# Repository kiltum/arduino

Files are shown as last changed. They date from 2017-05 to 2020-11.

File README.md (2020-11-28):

# Arduino shield for automation purposes

ATTN: This is picture of very old board. I havent new pictures

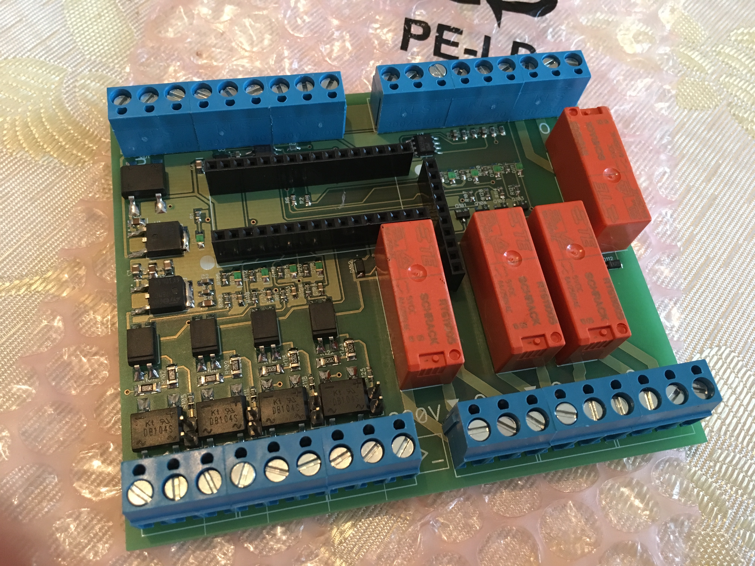
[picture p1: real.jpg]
Ready for using


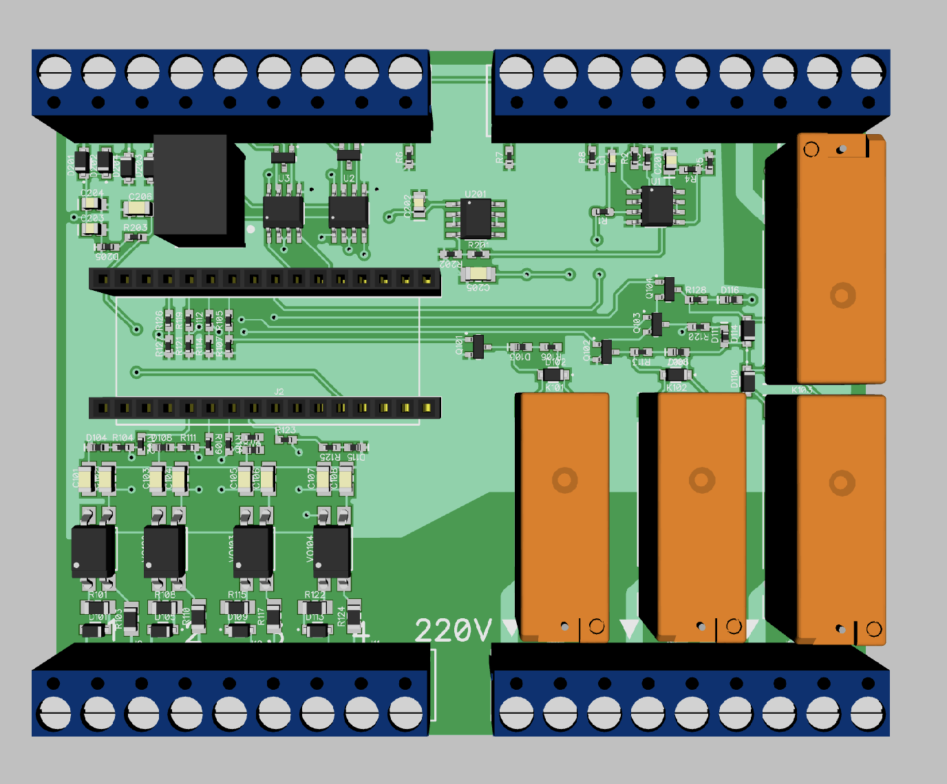
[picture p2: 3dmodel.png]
How it should look


What this shield can do?
- Work with any Arduino Nano
- Work from 15-30 AC/DC. 
- Have 4x220v sensor
- Have 4x8A switch relay
- Have 0-10V output
- Have two RS-485
- 3 PT1000/pulled down analog input

## Pin-out for auduio

- D2,D3,D4 - TX,RX and RE/DE of 485
- D11, D12, D13 - for second 485
- D5 - PWM output for 0-10V
- D6 - PWM output for second 0-10V
- D7-D10 - control for switch relay 1-4
- A4,A5,A6,A7 - pulled down input for PT1000
- A0-A3 - sensors input

## Pin-out for board

Take board like on picture

### Top. Left-to-right

- 1 - power in POSITIVE
- 2 - GND
- 3 - RS485B
- 4 - RS485A
- 5 - RS485B2
- 7 - RS485A2
- 6 - GND
- 8 - 5V
- 9 - A4

separator

- 10 - A5
- 11 - A6 
- 12 - A7
- 13 - 0-10V output 2
- 14 - 0-10V output 1
- 15 - GND
- 16 - R4 closed
- 17 - R4 open	
- 18 - R4 ground

### Bottom, left to right

- 1 - Sensor 1 220V / 24V Positive
- 2 - Sensor 1
- 3 - Sensor 2 220v / 24V Positive
- 4 - Sensor 2
- 5 - Sensor 3 220v / 24V Positive
- 6 - Sensor 3
- 7 - Sensor 4 220v / 24V Positive
- 8 - Sensor 4
- 9 - not connected

separator

- 10 - R1 ground
- 11 - R1 closed
- 12 - R1 open
- 13 - R2 ground 
- 14 - R2 closed
- 15 - R2 open
- 16 - R3 ground
- 17 - R3 close
- 18 - R3 open

## License

Do what you want. I do not rely for anything you do.

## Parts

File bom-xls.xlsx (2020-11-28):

Value | RefDes | Pattern | LCSC
100nF | C1, C2 | CAP-0402-N | C1525
47uF | C101, C102, C103, C104, C105, C106, C107, C108, C205, C206 | CAP-1206 | C96123
2.2uF | C201, C202, C203, C204 | CAP-0805 | C49217
 | D1, D2, D3, D4 | SMB | C78395
 | D101, D105, D109, D113 | SMA | C95872
 | D102, D106, D110, D114 | SOD-123F | C8598
 | D103, D104, D107, D108, D111, D112, D115, D116, D202 | DIO-0603 | C2286
 | D201 | SMA | C412437
 | Q101, Q102, Q103, Q104 | SOT23 | C8545
100k | R1, R4 | RES-0402-N | C25741
4.7k | R2, R3, R5, R6, R7, R8, R9, R10, R101, R108, R109, R116, R117, R124, R125, R131 | RES-0402-N | C25900
82k | R102, R103, R110, R111, R118, R119, R126, R127 | RES-0805-N | C17840
180 | R104, R106, R112, R115, R120, R123, R128, R132, R203, R204, R205 | RES-0402-N | C25762
1k | R105, R113, R121, R130, R202 | RES-0402-N | C11702
12k | R107, R114, R122, R129 | RES-0402-N | C25752
2k | R201 | RES-0402-N | C4109
 | U1 | SOIC-8 | C18229
 | U2, U3 | SOIC-8 | C7063
 | U4, U5 | SOT23 | C32677
 | U201 | DPAK3P228-991X238L51X76T645X546L-AP1 | C75510
 | VO101, VO102, VO103, VO104 | SOP4-6P254-360X700X285L50X40L | C6649

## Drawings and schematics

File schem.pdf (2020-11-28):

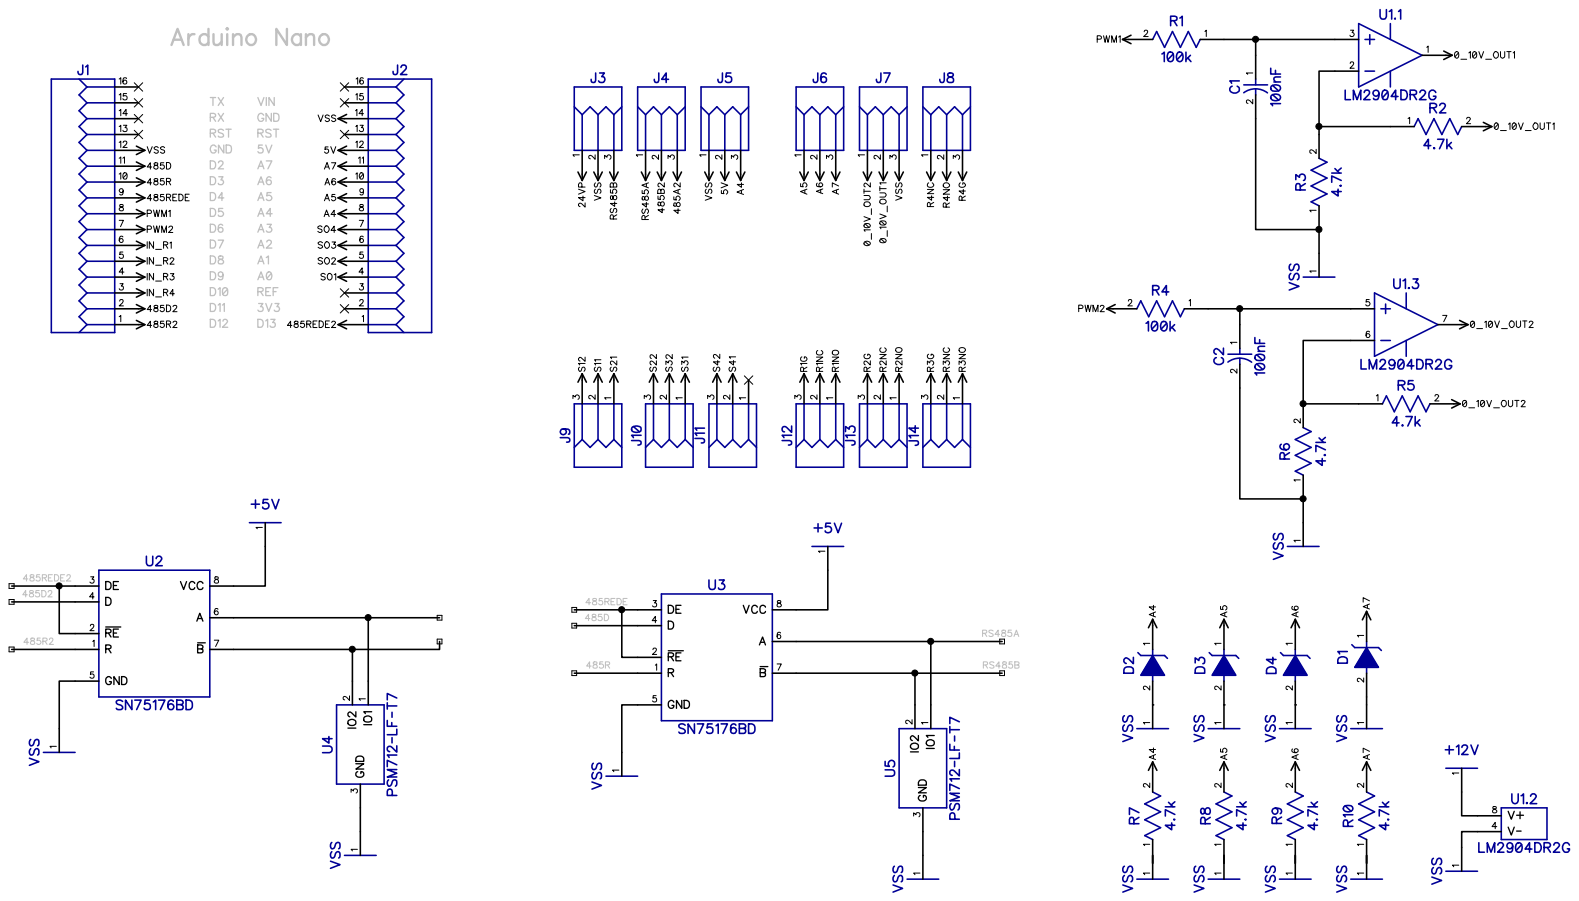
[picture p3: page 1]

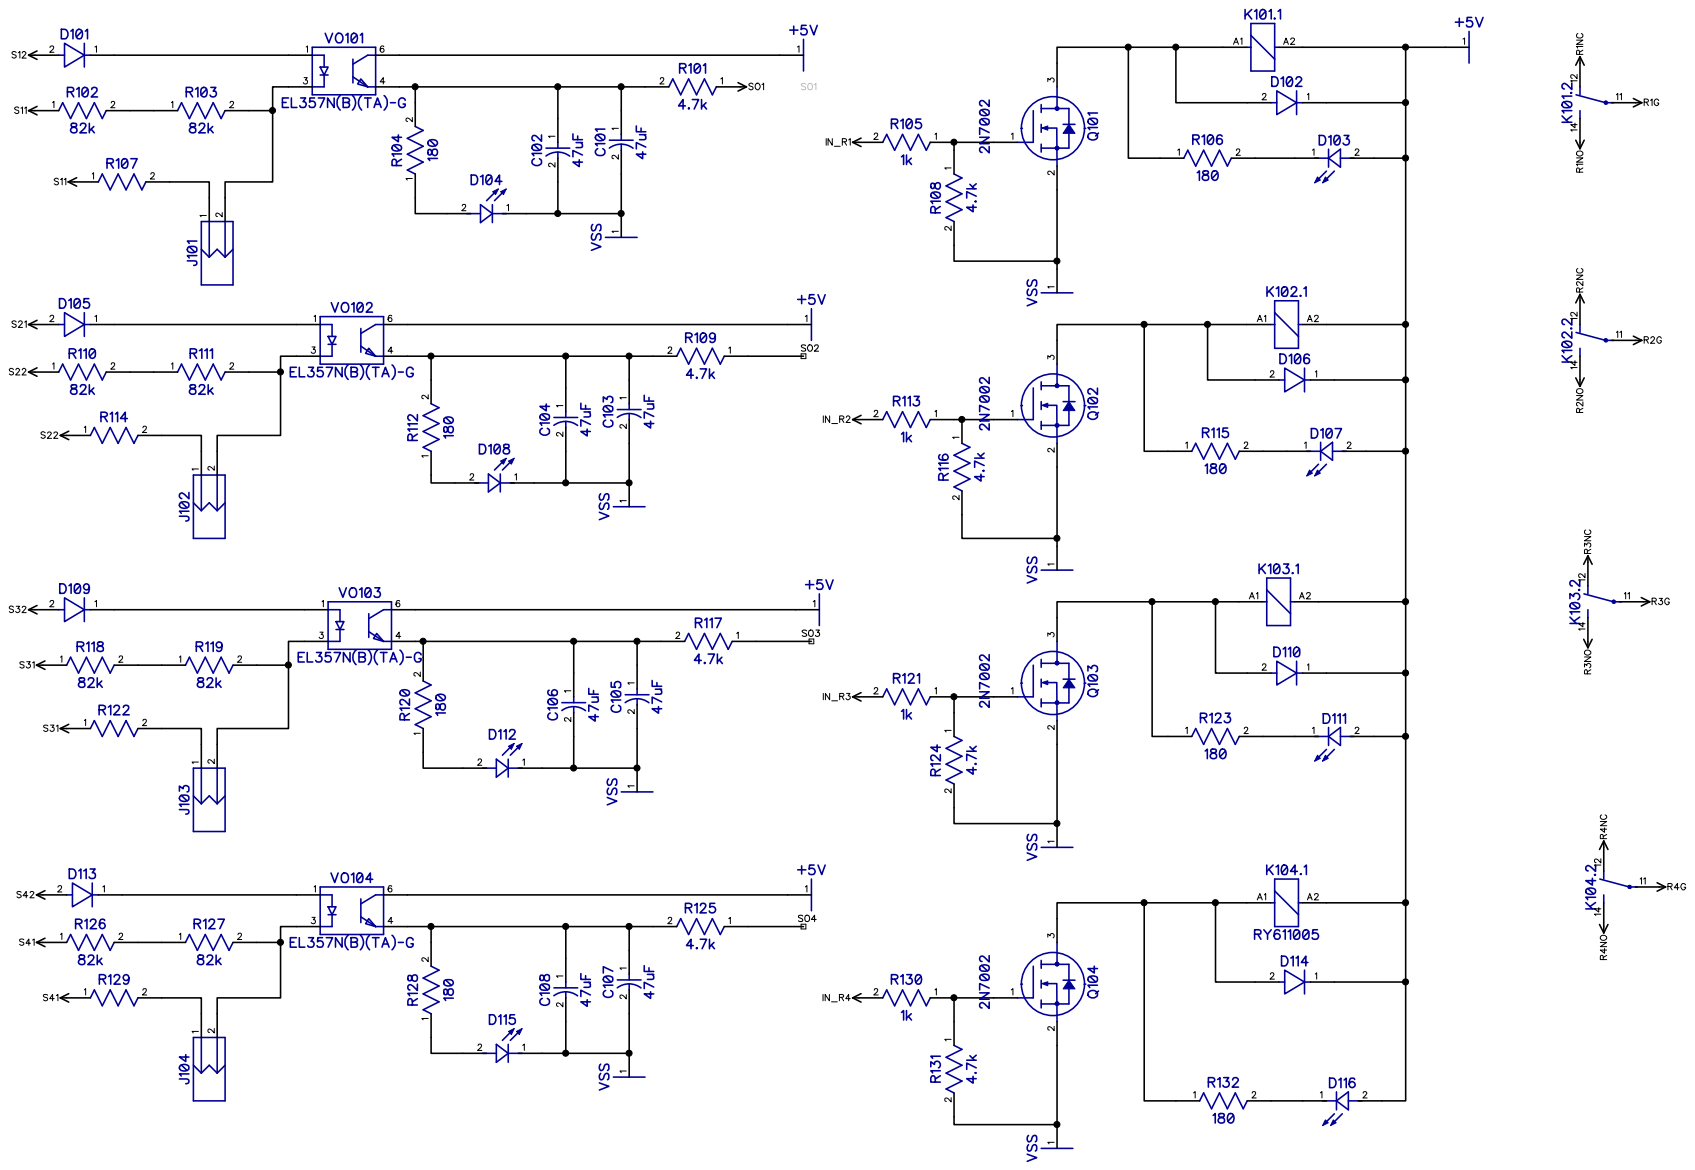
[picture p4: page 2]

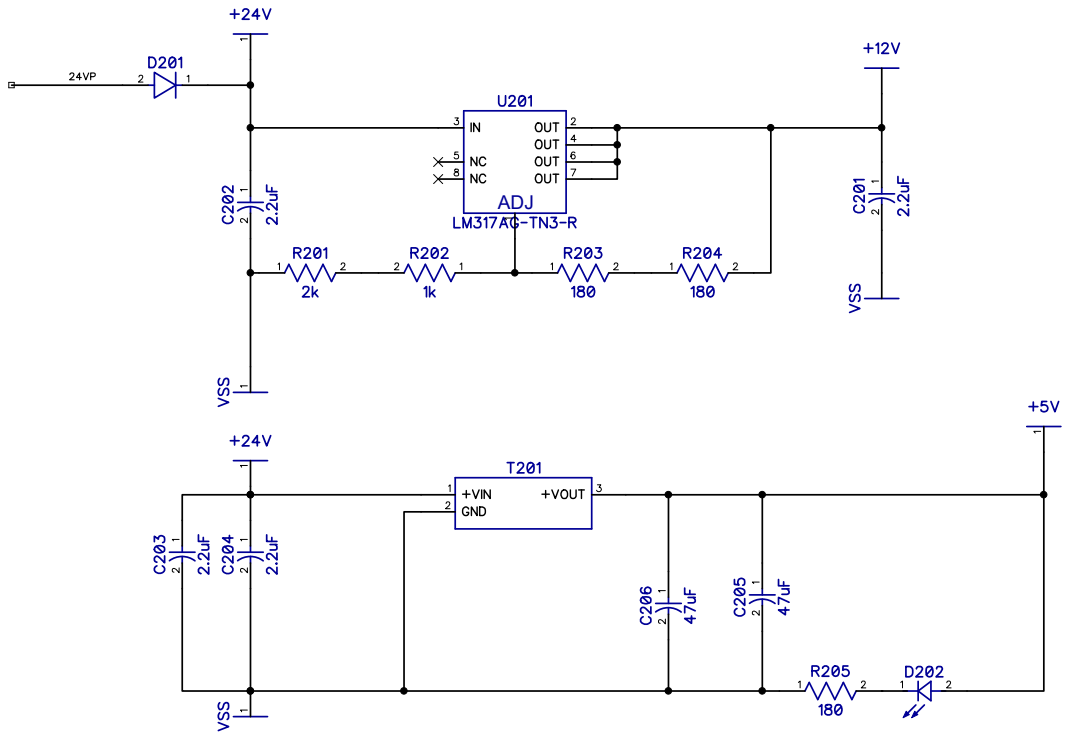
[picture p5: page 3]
ADJ

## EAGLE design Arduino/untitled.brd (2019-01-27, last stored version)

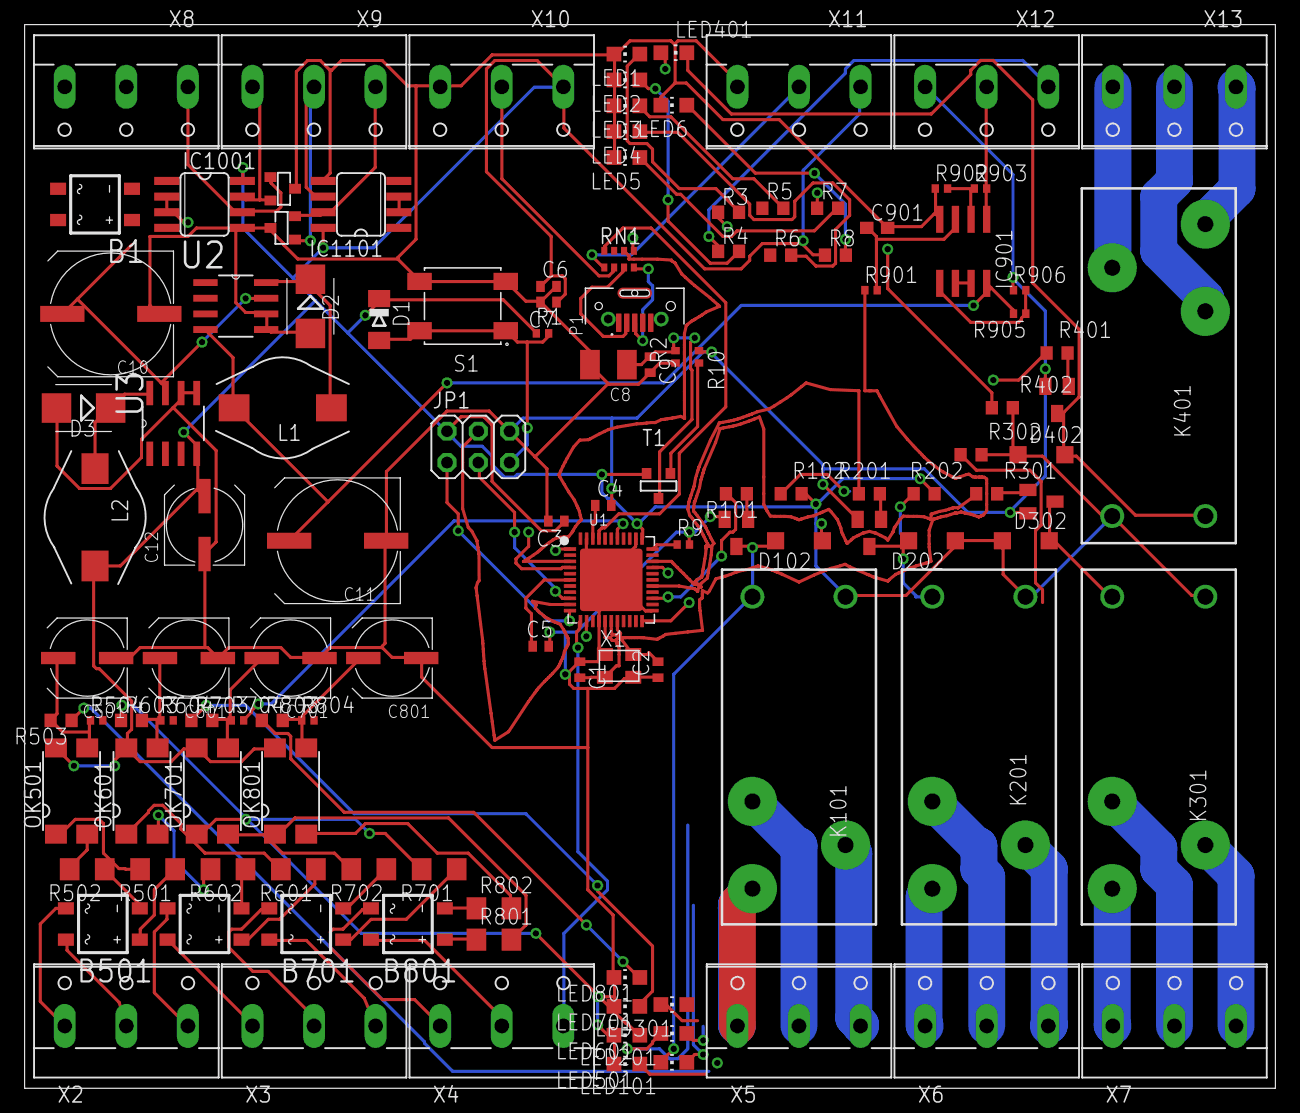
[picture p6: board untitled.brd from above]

Board: 4 copper layers, 101.5 x 86.3 mm, 122 parts (0 on the bottom side), 118 nets.

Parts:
B1, B501, B601, B701, B801: B6S; MBS
C1, C2: 22pF; C0402
C3, C5: 1uF; C0402
C4, C6, C7, C9: 100n; C0402
C8: 22u; SMC_B
C10, C11: 220uFx35V; UD-10X10_NICHICON
C12: 220uFx10; UD-6,3X5,8_NICHICON
C501, C601, C701, C801: 100uFx6,3; UD-6,3X5,8_NICHICON
C901: 0.1uF; C0603
D1: CD1206-S01575; MINIMELF
D2, D3: MBRS130LT3; SMB
D102, D202, D302, D402: MBR0520LT; SOD123
D1001, D1101: CDSOT23-SM712; SOT-23-3
IC901: LM2904; SO08
IC1001, IC1101: MAX481CSA; SO08
JP1: 3x2M; 2X03
K101, K201, K301, K401: RT174005; RT-C/O12A3.5
L1: DO3308P-334MLD; BOURNS_SRR0805
L2: DO3316-224; BOURNS_SRR0805
LED1, LED2, LED3, LED4, LED5, LED6, LED101, LED201, LED301, LED401, LED501, LED601, LED701, LED801: IN-S85AT5B; CHIP-LED0805
OK501, OK601, OK701, OK801: LTV816S; SMD4
P1: KMMVX-SMT-BS-BTR; KYCON_KMMVX-SMT-BS-BTR
Q101, Q201, Q301, Q401: BSS138L
R1, R2, R9, R10, R504, R604, R704, R804: 10K; R0402
R3, R4, R5, R6, R7, R8, R102, R202, R302, R402, R503, R603, R703, R803: 600; R0603
R101, R201, R301, R401: 1K; R0603
R501, R502, R601, R602, R701, R702, R801, R802: 82K; R1206
R901: 10k; R0402
R902, R903, R905, R906: 4.7k; R0402
RN1: 22R; CAY16
S1: 430481035816_430481035816; 430481035816
T1: FDN340P/PMV48XP; SOT-23
U1: MCU-ATMEGA32U4-MUR(VQFN44); QFN44G-0.5-7X7MM
U2: LM2594M-12; SOIC127P620X175-8N
U3: LM2594M-05; SOIC127P620X175-8N
X1: 16MHz KX-7; CRYSTAL-3.2-2.5
X2, X3, X4, X5, X6, X7, X8, X9, X10, X11, X12, X13: W237-103

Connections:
0-10V1:N$1: IC901.5, R905.1, R906.2
0-10V1:N$2: C901.1, IC901.3, R901.2
0-10V1:N$3: IC901.6, IC901.7
0-10V1:N$4: IC901.2, R902.2, R903.1
10V1: IC901.1, R903.2, X12.2
24V1: B1.AC1, X8.3
24V2: B1.AC2, X8.2
+5V: C3.1, C6.1, C7.1, C12.+, D1.C, D102.C, D202.C, D302.C, D402.C, IC1001.8, IC1101.8, JP1.2, K101.A2, K201.A2, K301.A2, K401.A2, L2.2, OK501.4, OK601.4, OK701.4, OK801.4, R1.1, R8.1, R102.2, R202.2, R302.2, R402.2, T1.2, U1.2, U1.14, U1.24, U1.34, U1.44, U3.4, X10.1, X11.1
+12V: C11.+, IC901.8, L1.2, R905.2, U2.4
A0/S1: R504.2, U1.36
A1/S2: R604.2, U1.37
A2/S3: R704.2, U1.38
A3/S4: R804.2, U1.39
A4: RN1.3, U1.40
A4O: RN1.6, X10.2
A5: RN1.4, U1.41
A5O: RN1.5, X11.2
AREF: C4.1, U1.42
D0/RX/RS485R2: IC1101.1, U1.20
D1/TX/RS485D2: IC1101.4, U1.21
D2/SDA/RS485REDE2: IC1101.2, IC1101.3, U1.19
D3/SCL/PWM: R901.1, U1.18
D4/R1: R101.1, U1.25
D5/R2: R201.1, U1.31
D6/R3: R301.1, U1.27
D7/R4: R401.1, U1.1
D+: P1.3, RN1.8
D-: P1.2, RN1.7
GND: B1.-, C1.1, C2.1, C3.2, C4.2, C5.2, C6.2, C7.2, C8.-, C9.2, C10.-, C11.-, C12.-, C501.-, C601.-, C701.-, C801.-, C901.2, D2.A, D3.A, D1001.3, D1101.3, IC901.4, IC1001.5, IC1101.5, JP1.6, LED1.C, LED2.C, LED3.C, LED4.C, LED5.C, LED6.C, LED501.C, LED601.C, LED701.C, LED801.C, P1.5, Q101.S, Q201.S, Q301.S, Q401.S, R2.1, R9.2, R10.1, R902.1, R906.1, S1.3, S1.4, U1.5, U1.15, U1.23, U1.35, U1.43, U1.TAB, U2.5, U2.6, U3.5, U3.6, X1.2, X1.4, X10.3, X11.3, X12.3
HWB: R9.1, U1.33
IO8/RS485R1: IC1001.1, U1.28
IO9/RS485D1: IC1001.4, U1.29
IO10/RS485REDE1: IC1001.2, IC1001.3, U1.30
IO11: R3.1, U1.12, X4.3
IO12: R4.1, U1.26, X12.1
IO13: R5.1, U1.32
MISO: JP1.1, U1.11
MOSI: JP1.4, U1.10
unnamed: B1.+, C10.+, U2.7, U3.7
unnamed: D2.C, L1.1, U2.8
unnamed: LED3.A, R5.2
unnamed: LED4.A, R6.2
unnamed: LED5.A, R7.2
unnamed: D3.C, L2.1, U3.8
unnamed: LED6.A, R8.2
unnamed: R10.2, T1.3
unnamed: LED2.A, R4.2
unnamed: LED1.A, R3.2
R1G: K101.11, X5.3
R1NC: K101.12, X5.2
R1NO: K101.14, X5.1
R2G: K201.11, X6.3
R2NC: K201.12, X6.2
R2NO: K201.14, X6.1
R3G: K301.11, X7.3
R3NC: K301.12, X7.2
R3NO: K301.14, X7.1
R4G: K401.11, X13.3
R4NC: K401.12, X13.2
R4NO: K401.14, X13.1
RD+: RN1.1, U1.4
RD-: RN1.2, U1.3
RELAY1:N$1: D102.A, K101.A1, LED101.C, Q101.D
RELAY1:N$2: LED101.A, R102.1
RELAY1:N$4: Q101.G, R101.2
RELAY2:N$1: D202.A, K201.A1, LED201.C, Q201.D
RELAY2:N$2: LED201.A, R202.1
RELAY2:N$4: Q201.G, R201.2
RELAY3:N$1: D302.A, K301.A1, LED301.C, Q301.D
RELAY3:N$2: LED301.A, R302.1
RELAY3:N$4: Q301.G, R301.2
RELAY4:N$1: D402.A, K401.A1, LED401.C, Q401.D
RELAY4:N$2: LED401.A, R402.1
RELAY4:N$4: Q401.G, R401.2
RESET: D1.A, JP1.5, R1.2, S1.1, S1.2, U1.13
RS485A1: D1001.2, IC1001.7, X9.3
RS485A2: D1101.2, IC1101.7, X9.1
RS485B1: D1001.1, IC1001.6, X8.1
RS485B2: D1101.1, IC1101.6, X9.2
RXLED/SS: R6.1, U1.8
S11: B501.AC1, X2.2
S12: B501.AC2, X2.1
S21: B601.AC1, X3.1
S22: B601.AC2, X2.3
S31: B701.AC1, X3.3
S32: B701.AC2, X3.2
S41: B801.AC1, X4.2
S42: B801.AC2, X4.1
SCK: JP1.3, U1.9
SENSE1:N$2: LED501.A, R503.1
SENSE1:N$3: B501.+, R501.1
SENSE1:N$4: OK501.1, R501.2
SENSE1:N$5: OK501.2, R502.2
SENSE1:N$6: B501.-, R502.1
SENSE1:N$10: C501.+, OK501.3, R503.2, R504.1
SENSE2:N$2: LED601.A, R603.1
SENSE2:N$3: B601.+, R601.1
SENSE2:N$4: OK601.1, R601.2
SENSE2:N$5: OK601.2, R602.2
SENSE2:N$6: B601.-, R602.1
SENSE2:N$10: C601.+, OK601.3, R603.2, R604.1
SENSE3:N$2: LED701.A, R703.1
SENSE3:N$3: B701.+, R701.1
SENSE3:N$4: OK701.1, R701.2
SENSE3:N$5: OK701.2, R702.2
SENSE3:N$6: B701.-, R702.1
SENSE3:N$10: C701.+, OK701.3, R703.2, R704.1
SENSE4:N$2: LED801.A, R803.1
SENSE4:N$3: B801.+, R801.1
SENSE4:N$4: OK801.1, R801.2
SENSE4:N$5: OK801.2, R802.2
SENSE4:N$6: B801.-, R802.1
SENSE4:N$10: C801.+, OK801.3, R803.2, R804.1
TXLED: R7.1, U1.22
UCAP: C5.1, U1.6
VUSB: C8.+, C9.1, P1.1, R2.2, T1.1, U1.7
XTAL1: C2.2, U1.17, X1.3
XTAL2: C1.2, U1.16, X1.1

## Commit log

2017-03-04 power done
2017-03-04 All done, but need nice touches like labeling
    [bom.csv]
2017-03-05 fix stupid error
    [Board.gbr, BoardOutline.gbr, Bottom.gbr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]
2017-03-05 forget to out DQ
    [Board.gbr, BoardOutline.gbr, Bottom.gbr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]
2017-03-05 updated bom
    [bom.csv]
2017-03-07 New version. Now inputs can handle 24V too
    [Board.gbr, BoardOutline.gbr, Bottom.gbr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]
2017-03-15 New PWM values & board
    [BoardOutline.gbr, Bottom.gbr, BottomAssy.gbr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]
2017-03-27 another version
    [bom.csv]
2017-04-09 New gerber & bom
    [Board.gbr, BoardOutline.gbr, Bottom.gbr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]
2017-04-26 ready to prod
    [bom.xlsx]
2017-06-30 Clean up from oldies
    [bom.csv, bom.xlsx, ext_bom.csv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]
2017-06-30 new power
2017-07-09 New version
    Chnage power scheme
    [Board.gbr, BoardOutline.gbr, Bottom.gbr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]
2017-07-09 add bom
    [bom.csv]
2017-07-10 one more version
    [Board.gbr, BoardOutline.gbr, Bottom.gbr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]
2019-01-20 ne scheme from eagle
    [untitled.brd, untitled.sch]
2019-01-27 schem look done
    [untitled.brd, untitled.sch]
2019-01-27 first try:
    [untitled.brd, untitled.sch]
2019-02-10 12V part redesign
    [WBBOMDesign22.csv]
2019-02-10 first step on chem done
    [WBBOMDesign22(1).csv]
2019-02-10 first build
    [bom.csv]
2019-02-23 remove old
    [WBBOMDesign22(1).csv, WBBOMDesign22.csv, untitled.brd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]
2019-02-23 try to use pcbway
    [BOM_PCBWay.xlsx]
2019-02-24 move to old gerber
    [Board.gbr, BoardOutline.gbr, Bottom.gbr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]
2020-10-25 loks like final
    [BOM_PCBWay.xlsx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]
2020-11-28 rewrite schematics for jclpcb
2020-11-28 Return two -10V
2020-11-28 remove diodes
2020-11-28 ready for route?
    [bom.csv]
2020-11-28 try to send to jclpcb
    [bom.csv, bom_xls.xlsx, pnp.csv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]
2020-11-28 try to upload to jclpcb
    [bom-xls.xlsx, bom.csv, bom_xls.xlsx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]
2020-11-28 next try
    [pnp-xls.xlsx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]
2020-11-28 remove trash
    [pnp-xls.xlsx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]
